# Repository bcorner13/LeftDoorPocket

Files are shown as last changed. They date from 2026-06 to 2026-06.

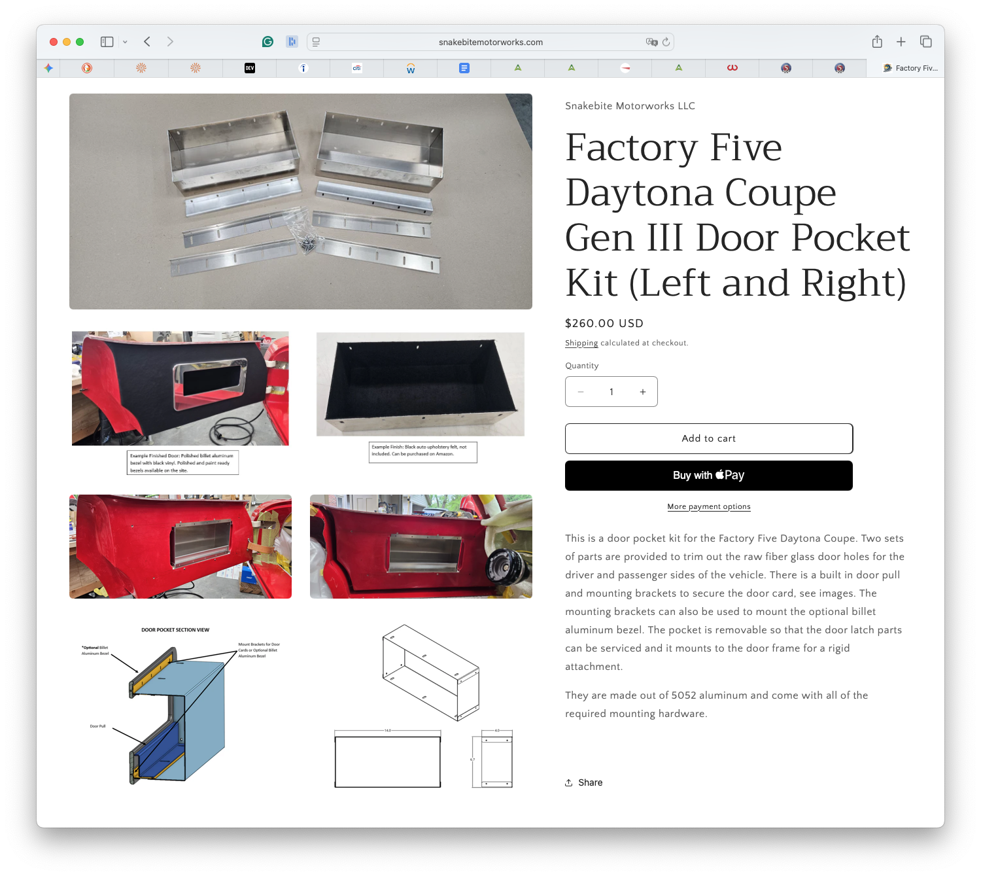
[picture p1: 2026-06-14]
images/Screenshot 2026-03-26 at 10.01.16 PM.png

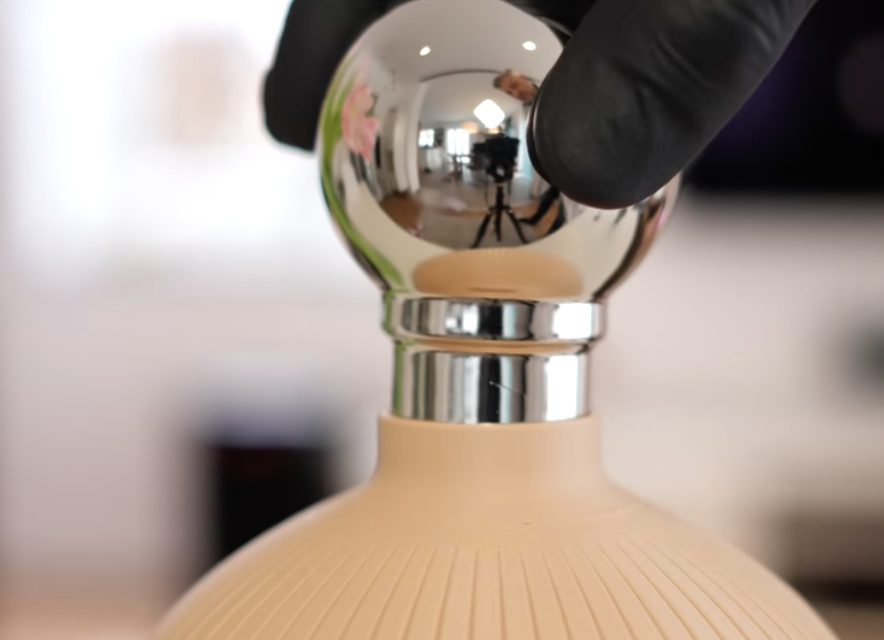
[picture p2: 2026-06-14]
images/Screenshot 2026-03-26 at 10.39.22 PM.png

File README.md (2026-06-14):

# Left Door Pocket

Parametric storage pocket / organizer for the **inside of a Daytona Coupe driver-side
door**, designed against a 3D scan of the door panel. Multi-part printed assembly
(pocket + backing plate + two modular accessories) joined with M4 heat-set inserts and
screws.

Built and printed on the **Creality K2 Plus** (PLA for test, engineering plastic for
production), per the workspace standards in `CAD_STANDARDS.md`.

## Status

- **Canonical file:** `Assembly.FCStd` (FreeCAD 1.1.2 Assembly workbench).
- Geometry + assembly complete. **Active phase: K2 Plus build-plate fit** — the
  DoorPocket and BackingPlate are 392 mm in X (42 mm over the 350 mm bed).
- **Parametric backlog:** 127 unbound dimensions across the three part files; only the
  print-bed visualization is parametric so far. See `STATE.md` and `plan.md`.

## Layout

```
LeftDoorPocket/
├── Assembly.FCStd          ← canonical top-level assembly
├── Params.FCStd            ← VarSet for cross-doc parametric expressions
├── Left Door Pocket V1.3.FCStd  ← legacy single-doc fallback (do not work in)
├── parts/                  ← per-part source bodies (DoorPocketSet, Accessory_1/2)
├── archive/                ← historical V1.0–V1.2 versions (do not touch)
├── cad_files/              ← door 3D-scan reference (.stl, .mlp)
├── macros/                 ← project .FCMacro files
├── scripts/                ← audit_parametric.py and utilities
├── 3mf/  stl/              ← print deliverables (tracked)
├── gcode/                  ← slicer output (gitignored, regenerable)
├── images/                 ← screenshots / renders
├── intent.md  plan.md  STATE.md   ← goal, plan, detailed living state
└── CLAUDE.md + standards docs      ← project + workspace rules
```

## Working in this project

1. Open `Assembly.FCStd` (it pulls in the 4 source docs via App::Link) and double-click
   the `Assembly` node to make it active.
2. All geometry must stay parametric — read `CLAUDE.md` before any change.
3. After any edit: `python3 scripts/audit_parametric.py` (authoritative; fix violations
   before committing).
4. Write changes as macros under `macros/`, not by editing FCStd XML.

See `STATE.md` for assembly architecture, lessons learned, and the full next-session
checklist.

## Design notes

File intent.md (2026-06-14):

# intent.md — Left Door Pocket

## Goal

A parametric storage pocket / organizer that mounts to the **inside of a Daytona Coupe
driver-side (left) door**, designed to fit the door panel captured by 3D scan
(`cad_files/Daytona Coupe Inside door.stl`).

The deliverable is a multi-part printed assembly:
- **DoorPocket** — the main pocket body (base, walls, internal cavity)
- **BackingPlate** — mounts the pocket to the door, carries 16 M4 heat-set inserts
- **Accessory_1 / Accessory_2** — modular insert accessories that seat in the pocket
- Hardware: 16× M4×8.15 heat inserts (press-fit, permanent) + 16× M4×25 screws (removable)

## Constraints

- Must follow `CAD_STANDARDS.md` (mm units, manifold geometry, Part/PartDesign).
- Must follow the parametric rules in `CLAUDE.md` / `~/.claude/CLAUDE.md`:
  everything driven by `Params.FCStd` VarSet, no literal sketch constraints,
  datum-plane attachment, decoupled per-interface clearances.
- Printable on the **Creality K2 Plus** (350×350×350 mm build volume).
  - ⚠️ Current DoorPocket and BackingPlate are **392 mm in X — 42 mm too long** for
    the bed. Resolving this (diagonal print vs. midline split) is the active next phase.
- Peg-in-hole and screw interfaces must use print-fit clearances (FDM-tolerant),
  not geometric tightness.

## Status

Geometry and the 1.1.2 Assembly are built (`Assembly.FCStd` canonical).
Remaining work: K2 Plus build-plate fit, then the parametric refactor backlog
(127 unbound dimensions across the three part files). See `plan.md` and `STATE.md`.

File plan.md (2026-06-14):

# plan.md — Left Door Pocket

> **Note:** This is a *retrofit* plan. The geometry and assembly already exist
> (built across sessions through 2026-05-10). This document records the realized
> design plus the remaining roadmap, so future sessions don't re-derive it.
> `STATE.md` holds the detailed, living state; this is the bootstrap-required plan view.

## PARAMETERS

Current `Params.FCStd` VarSet (3 properties — build-volume visualization only):

| Name | Type | Default | Purpose |
|---|---|---|---|
| `PrintBedX` | App::PropertyLength | 350 mm | K2 Plus build volume X |
| `PrintBedY` | App::PropertyLength | 350 mm | K2 Plus build volume Y |
| `PrintBedZ` | App::PropertyLength | 350 mm | K2 Plus build volume Z |

Parametric backlog — Params to add during the refactor (per `CLAUDE.md`):
- Pocket envelope: `LengthX`, `LengthY`, `HeightZ`, `WallThick`, `BaseThick`
- Pegs: `PegD`, `PegLength`, `PegOffsetX`, `PegOffsetY`
- Inserts/screws: `InsertBoreD`, `InsertDepth`, `ScrewClearD`
- Clearances (decoupled, one per interface):
  - `PegFitClearance` — peg-into-hole print fit
  - `BoltHoleClearance` — screw-through clearance
  - `ClearanceSide` — geometric tightness (~0.05–0.1 mm), kept separate from print fits

## FEATURE TREE

```
Assembly.FCStd  (Assembly::AssemblyObject — top level)
├── L_DoorPocket          → DoorPocketSet#Body      (GROUNDED)
├── L_Accessory_1         → Accessory_1#Body002
├── L_Accessory_2         → Accessory_2#Body003
├── SubAsm_BackingPlate   (nested Assembly — rigid unit)
│   ├── L_BackingPlate    → DoorPocketSet#Body001
│   └── Insert × 16       (M4×8.15 heat inserts)
├── Screw × 16            (M4×25, removable group)
└── PrintBed_K2Plus       (Part::Box, parametric, hidden)

Per-part source docs (parts/):
- DoorPocketSet.FCStd → Body (DoorPocket) + Body001 (BackingPlate, cross-body SubShapeBinder)
- Accessory_1.FCStd   → Body002
- Accessory_2.FCStd   → Body003
```

## CONSTRAINT STRATEGY

- Each per-part FCStd is refactored body-by-body (start simplest: Accessory_1).
- Every dimensional constraint bound via `setExpression` to `<<Params>>#VarSet.<name>`.
- Sketches attached to **datum planes** (convert any feature-face attachments / Deactivated
  MapMode peg datums to origin-plane-offset datums with parametric offsets).
- Clearances decoupled per interface — never overload one clearance variable.
- App::Link components use `LinkTransform=True` so intrinsic placements compose.

## VALIDATION

1. `python3 scripts/audit_parametric.py` — must report zero issues per file
   (current backlog: 127 unbound across the three part docs).
2. Geometry watertight / manifold (CAD_STANDARDS.md).
3. Build-plate fit: each printable body ≤ 350 mm on the K2 Plus, OR a validated
   diagonal orientation / midline split.
4. Assembly recompute clean; exploded view resolves; no DAG warnings.

## ROADMAP (active → deferred)

1. **K2 Plus fit** (active) — diagonal-print test of the 392 mm DoorPocket/BackingPlate;
   fall back to a parametric midline split if artifacts are unacceptable.
2. **Parametric refactor** — body-by-body, audit-clean each before moving on.
3. **Assembly polish** — explicit fixed joints, per-step instruction screenshots.

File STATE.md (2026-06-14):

# LeftDoorPocket — Project State

**Last updated:** 2026-05-10 (end of restructure session)
**Canonical working file:** `Assembly.FCStd`
**Status:** Restructure complete. **Next phase: K2 Plus build-plate fit.**

## File layout

```
LeftDoorPocket/
├── Assembly.FCStd                              ← top-level Assembly (1.1.2 workbench)
├── Params.FCStd                                ← VarSet for cross-doc parametric expressions
├── Left Door Pocket V1.3.FCStd                 ← legacy fallback (DO NOT WORK IN)
├── Left Door Pocket V1.3.Session-2026-05-09.FCStd  ← snapshot taken before LCS strip
├── parts/
│   ├── DoorPocketSet.FCStd                     ← contains Body (DoorPocket) + Body001 (BackingPlate)
│   ├── Accessory_1.FCStd                       ← Body002
│   └── Accessory_2.FCStd                       ← Body003
├── archive/
│   ├── Left Door Pocket.FCStd
│   ├── Left Door Pocket V1.0/V1.1/V1.1_backup/V1.2.FCStd
├── assembly_placements.json                    ← sidecar: body Y=27.39 record
├── scripts/audit_parametric.py                 ← parametric debt auditor
├── macros/create_params.FCMacro                ← bootstrap macro for Params.FCStd
├── CLAUDE.md                                   ← project rules
├── CAD_STANDARDS.md                            ← commercial design rules
├── MCP_TOOLS_REFERENCE.md                      ← FreeCAD MCP tool reference
└── STATE.md                                    ← this file
```

## Assembly architecture

```
Assembly  (Assembly::AssemblyObject, internal name "AssemblyV2")
├── L_DoorPocket               (App::Link → DoorPocketSet#Body, GROUNDED)
├── L_Accessory_1              (App::Link → Accessory_1#Body002)
├── L_Accessory_2              (App::Link → Accessory_2#Body003)
├── SubAsm_BackingPlate        (Assembly::AssemblyObject — sub-assembly, rigid unit)
│   ├── L_BackingPlate         (App::Link → DoorPocketSet#Body001)
│   └── Insert × 16            (M4x8.15 heat inserts, Part::FeaturePython)
├── Screw × 16                 (M4x25 screws — selectable as group)
├── Joints / GroundedJoint     (L_DoorPocket grounded)
└── PrintBed_K2Plus            (Part::Box, parametric, hidden by default)
```

**Component counts** (verified via UtilsAssembly):
- Main assembly: 36 components total
- Sub-assembly: 17 components (1 BackingPlate + 16 inserts)

**Why this architecture:**
- `SubAsm_BackingPlate` is its own `Assembly::AssemblyObject` so it can have its **own nested exploded view** (separate the 16 inserts from the BackingPlate as a sub-step).
- Heat inserts are press-fit (permanent) → rigid sub-assembly with BackingPlate.
- Screws are removable → kept as individual main-assembly components so they can be selected as a group and dragged out.
- All link Placements composed correctly via `LinkTransform=True`. BackingPlate's intrinsic Y=27.39mm carries through automatically.

## Parametric state

`Params.FCStd` VarSet currently has **3 properties**:
- `PrintBedX`, `PrintBedY`, `PrintBedZ` — all 350mm (K2 Plus build volume)

Bound to `Assembly.FCStd:PrintBed_K2Plus` for build-volume visualization.

**Per-part files have NO parametric bindings yet**:
- `parts/DoorPocketSet.FCStd`: 72 unbound issues
- `parts/Accessory_1.FCStd`: 24 unbound issues
- `parts/Accessory_2.FCStd`: 31 unbound issues
- Total: **127 unbound dimensional constraints + DAG-risk attachments + unconstrained sketches**

These are the parametric refactor backlog. Run `python3 scripts/audit_parametric.py` for the full list.

## Known cosmetic issues (not blocking)

1. **Internal Name `AssemblyV2`** vs Label "Assembly" — caused by name-collision avoidance during the V1.3 App::Part → Assembly::AssemblyObject conversion. User sees correct label in the tree; only matters for scripting.
2. **`*.bin (0 bytes)` warnings on doc load** — empty SuppressedShape/InternalShape cache files left over from the per-part prune passes. Geometry resolves fine via recompute. To clean up: open each per-part FCStd, force a full recompute, save.
3. **`Assembly001` may reappear** if user runs `Assembly_CreateAssembly` again (creates a new empty Assembly with internal name "Assembly" since that's free). Just delete it from the tree.

## Lessons learned this session (worth remembering)

- **FreeCAD's RunInitGuiPy exec context** does NOT set `__file__` and does NOT share module-level names with class methods or deferred callbacks. Stub-loader pattern (separate `_workbench.py` exec'd from `InitGui.py` with explicit shared namespace) is the correct fix. Applied to `FreeCADMCPAgent` addon at both local + 5TB locations.
- **`App::Link` `LinkTransform`** defaults to `False` in 1.1, meaning the linked object's intrinsic Placement is NOT applied — only the link's own Placement. Set to `True` to compose properly. We hit this with the BackingPlate Y=27.39 ghost gap.
- **Assembly workbench requires `Assembly::AssemblyObject` typeId**, not `App::Part`. V1.3-era "Assembly" objects were App::Part shells — they LOOK assembly-like but `Assembly_CreateView`, `Assembly_CreateBom`, and joint commands stay grayed out.
- **Tree clicks don't register with the exploded-view dialog.** Selection paths must be rooted at the Assembly object name; clicking the App::Link in the tree generates a path rooted at the link, which `getComponentReference` rejects. **Always click on a face in the 3D view.**
- **`Assembly_InsertLink` GUI command and `addObject("App::Link")` produce equivalent components.** No metadata difference. The workbench identifies components by type + parent + LinkedObject.
- **Cross-body `SubShapeBinder`** in BackingPlate (binds outline to DoorPocket.Fillet001.Face27) is why we kept those two bodies in one FCStd file (`DoorPocketSet.FCStd`) rather than splitting them. Cross-doc binders work but add complexity; we'll revisit in the parametric pass.

## ⚠️ Build-plate fit assessment (next phase)

K2 Plus build volume: **350×350×350 mm**

| Part | Size (X×Y×Z mm) | Fits K2 Plus? |
|---|---|---|
| **DoorPocket** | **392 × 126 × 157** | ❌ **42mm too long in X** |
| **BackingPlate** | **392 × 9 × 157** | ❌ **42mm too long in X** |
| Accessory_1 | 69.7 × 70 × 35 | ✅ |
| Accessory_2 | 70 × 70 × 60 | ✅ |

**The two main bodies do not fit on the K2 Plus.** Options for next phase:

1. **Diagonal print** — 350√2 ≈ 495mm available across the bed diagonal. Need to verify print orientation works for the geometry (door pocket cavity opening, overhangs).
2. **Parametric scale-down** — make `LengthX` a Param and reduce. Affects functional fit on the actual door panel — probably non-starter without door-fit redesign.
3. **Split design** — divide DoorPocket and BackingPlate at midpoint with a mating interface (dovetail, dowels, glue joint). Two halves, each ≤200mm, joined post-print.
4. **Switch printer** — Saturn 4 is smaller (218×123×260 typical for Mk2/Ultra), so probably worse. No clear option here.

**Likely next-session direction:** option 1 first (cheapest test — just orientation), fall back to option 3 (design work) if angled printing introduces unacceptable artifacts on the door pocket cavity walls.

## Open follow-ups (for next session)

**Phase: K2 Plus fit**
- [ ] Test diagonal-orientation print of DoorPocket on K2 Plus (slicer simulation first)
- [ ] If diagonal fails → design a midline split for DoorPocket + matching BackingPlate split
- [ ] Verify Accessory_1, Accessory_2 print orientation (peg overhang, surface finish on cylinder side)

**Phase: parametric refactor (deferred)**
- [ ] Run audit, work body-by-body. Start with Accessory_1 (24 issues, simplest).
- [ ] Convert peg datums (`PegPlane_L`/`PegPlane_R`, `DP2_PegL`/`DP2_PegR`) from Deactivated MapMode to attached-to-origin-plane with parametric offsets.
- [ ] Bind every dimensional constraint via `setExpression` to `<<Params>>#VarSet.<name>`.
- [ ] Decouple clearances into per-interface vars: `PegFitClearance`, `BoltHoleClearance`.
- [ ] Re-run `scripts/audit_parametric.py` between bodies, target zero issues per file.

**Phase: assembly polish (low priority)**
- [ ] Add `Joint_Fixed` between L_DoorPocket and SubAsm_BackingPlate (replace the ad-hoc grounded-only setup with explicit kinematic constraints)
- [ ] Decide screw motion: keep them as individual movable components or group via fixed joints
- [ ] Build the per-step assembly-instruction screenshots (the documentation script)
- [ ] Optional: write the frame-export Python script for exploded-view animation

## How to resume next session

1. Open `Assembly.FCStd` (it auto-loads the 4 source docs via App::Link).
2. Double-click the `Assembly` node in the tree to make it active (FreeCAD doesn't persist active state).
3. Confirm the geometry looks right — DoorPocket grounded, BackingPlate sub-asm flush, accessories in their sockets.
4. Then start the K2 Plus fit work.

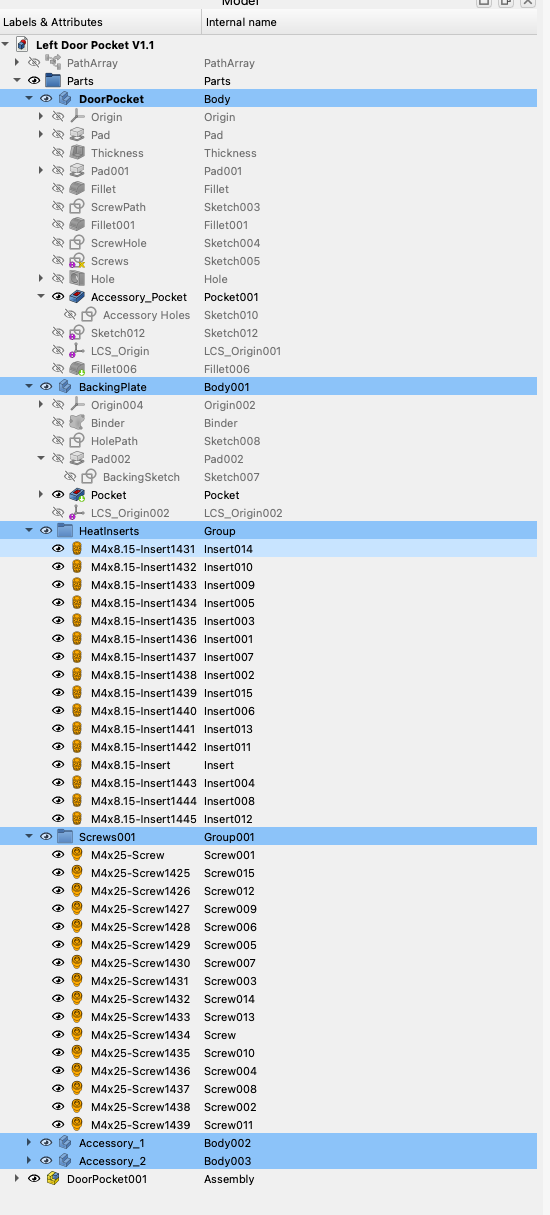
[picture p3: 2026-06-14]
images/Screenshot 2026-03-26 at 10.19.09 PM.png

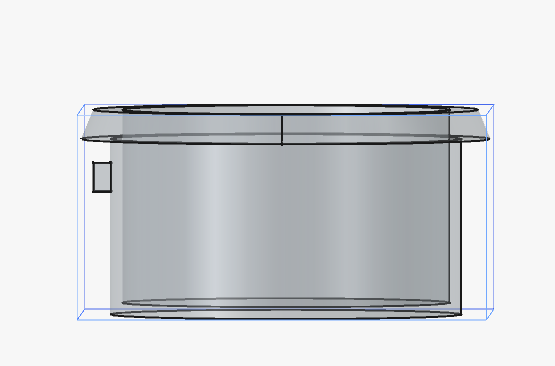
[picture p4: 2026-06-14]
images/Screenshot 2026-03-26 at 4.24.34 PM.png

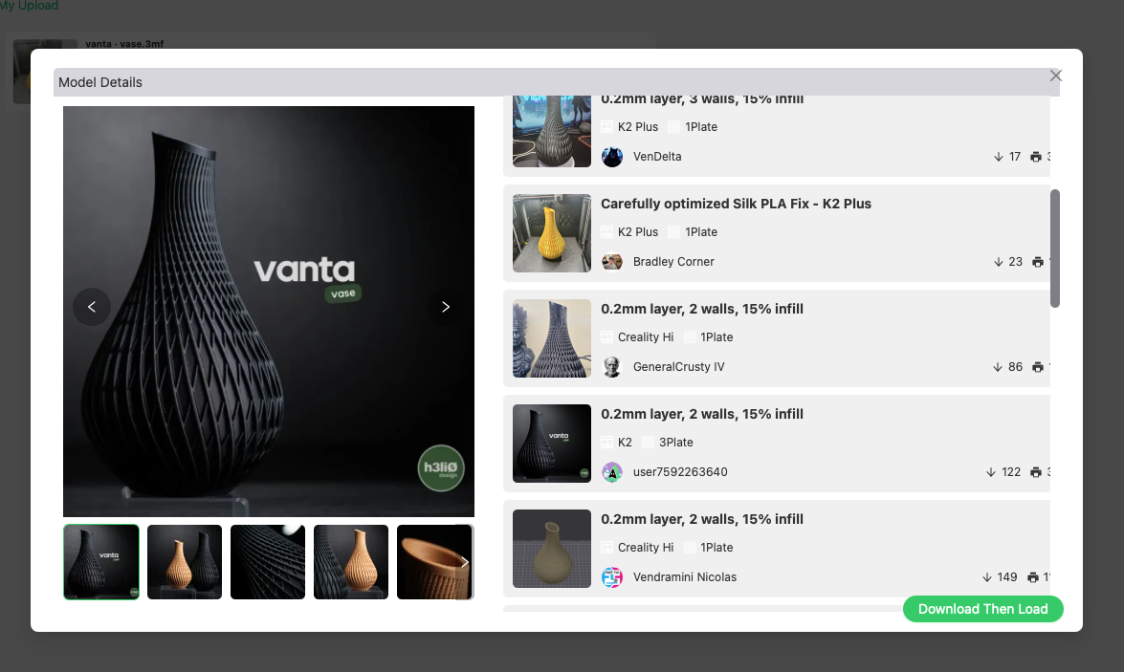
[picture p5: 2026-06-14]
images/Screenshot 2026-03-27 at 3.15.48 AM.png

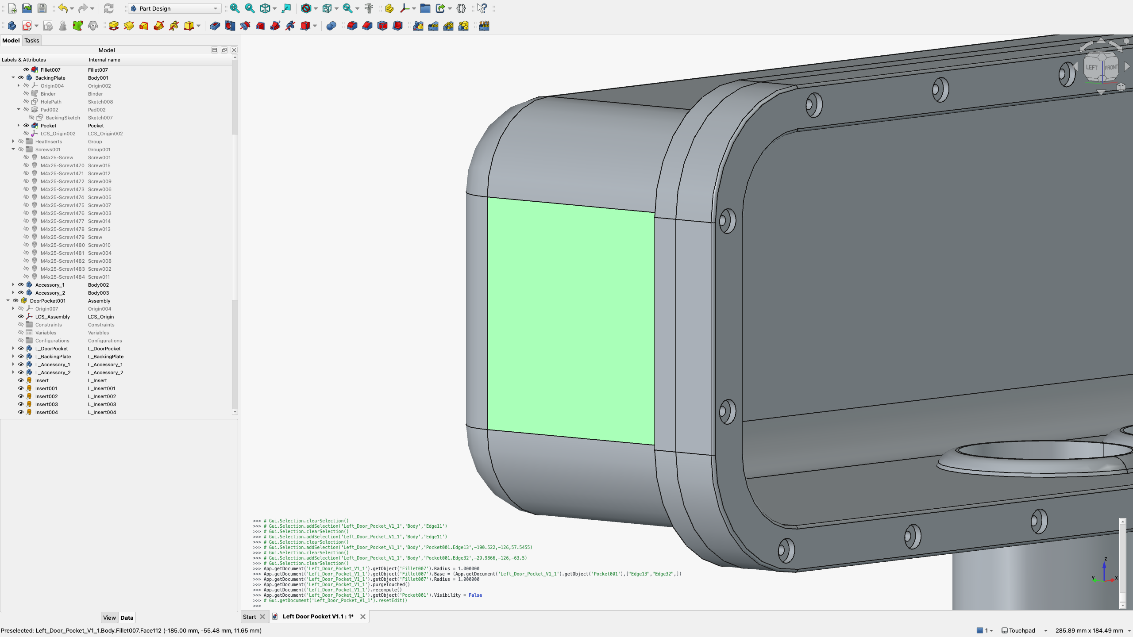
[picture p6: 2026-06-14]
images/Screenshot 2026-03-26 at 10.34.55 PM.png

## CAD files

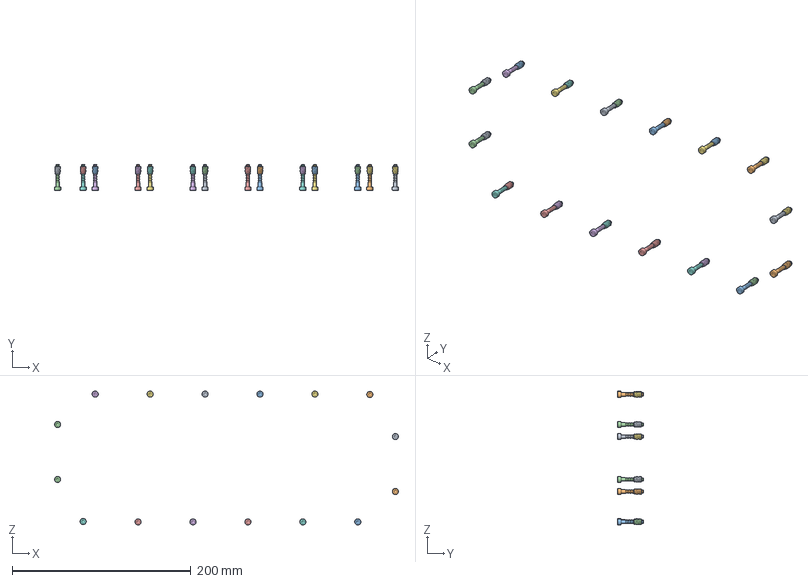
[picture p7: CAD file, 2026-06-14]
Assembly.FCStd
385.0 x 29.0 x 149.9 mm
M4x8.15-Insert1624
M4x8.15-Insert1620
M4x8.15-Insert1619
M4x8.15-Insert1615
M4x8.15-Insert1613
M4x8.15-Insert1611
M4x8.15-Insert1617
M4x8.15-Insert1612
M4x8.15-Insert1625
M4x8.15-Insert1616
M4x8.15-Insert1623
M4x8.15-Insert1621
M4x8.15-Insert
M4x8.15-Insert1614
M4x8.15-Insert1618
M4x8.15-Insert1622
M4x25-Screw
M4x25-Screw1589
M4x25-Screw1586
M4x25-Screw1583
M4x25-Screw1580
M4x25-Screw1579
M4x25-Screw1581
M4x25-Screw1577
M4x25-Screw1588
M4x25-Screw1587
M4x25-Screw1575
M4x25-Screw1584
M4x25-Screw1578
M4x25-Screw1582
M4x25-Screw1576
M4x25-Screw1585

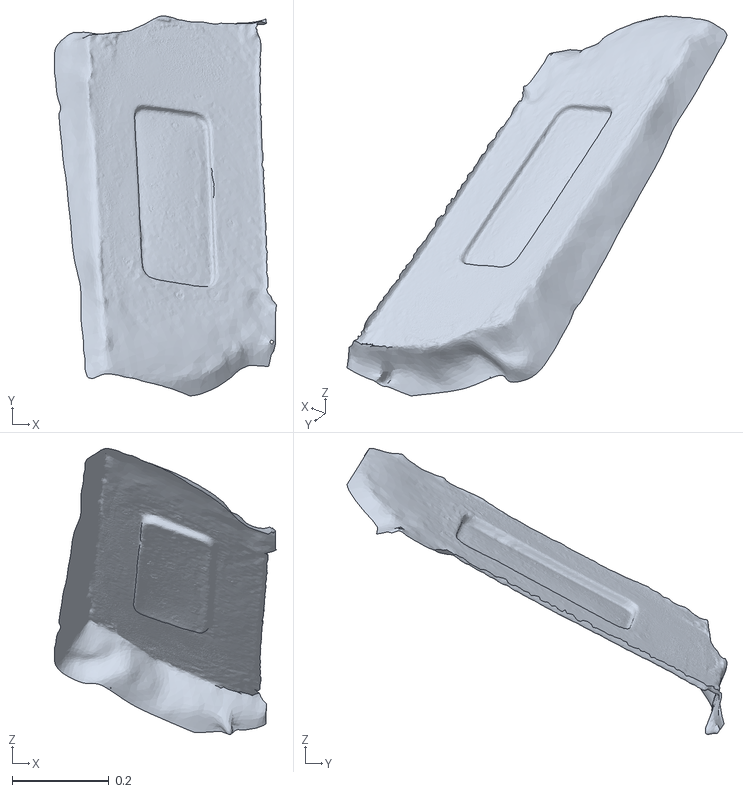
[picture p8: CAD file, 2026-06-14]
cad_files/Daytona Coupe Inside door.stl
0.461 x 0.787 x 0.593

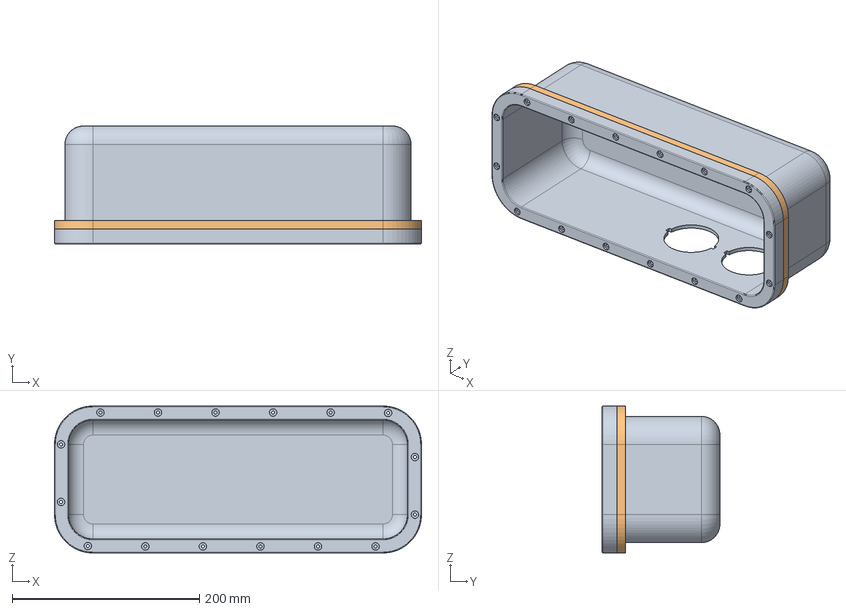
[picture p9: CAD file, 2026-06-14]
parts/DoorPocketSet.FCStd
392.0 x 126.0 x 157.0 mm
DoorPocket
BackingPlate

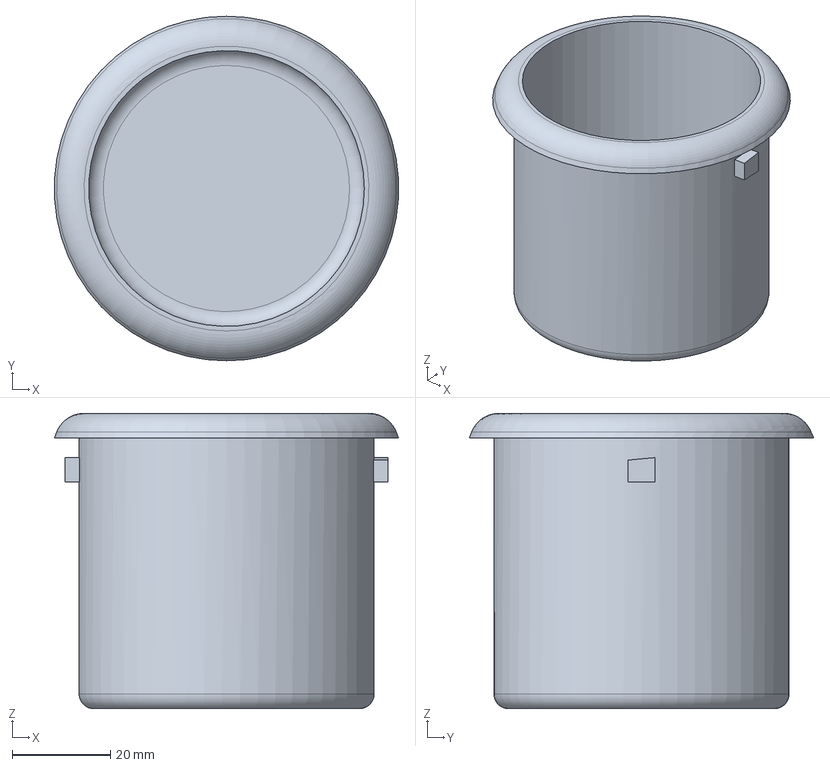
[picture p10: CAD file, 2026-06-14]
parts/Accessory_2.FCStd
69.9 x 70.0 x 60.0 mm

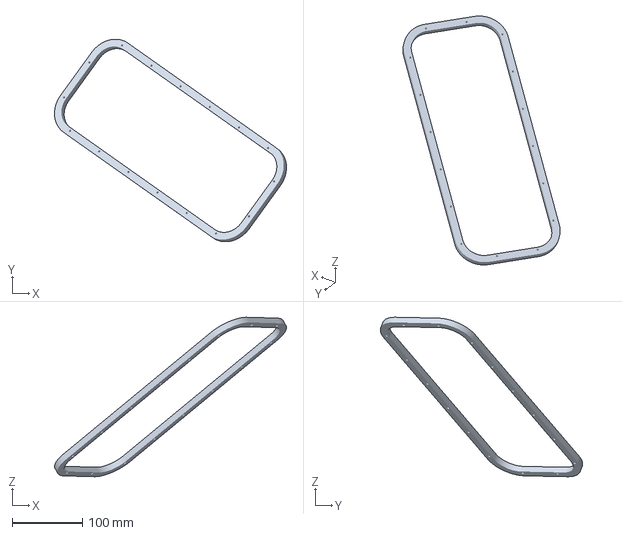
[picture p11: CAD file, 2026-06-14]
Left Door Pocket V1.1-BackingPlate.3mf
331.4 x 289.2 x 227.9 mm

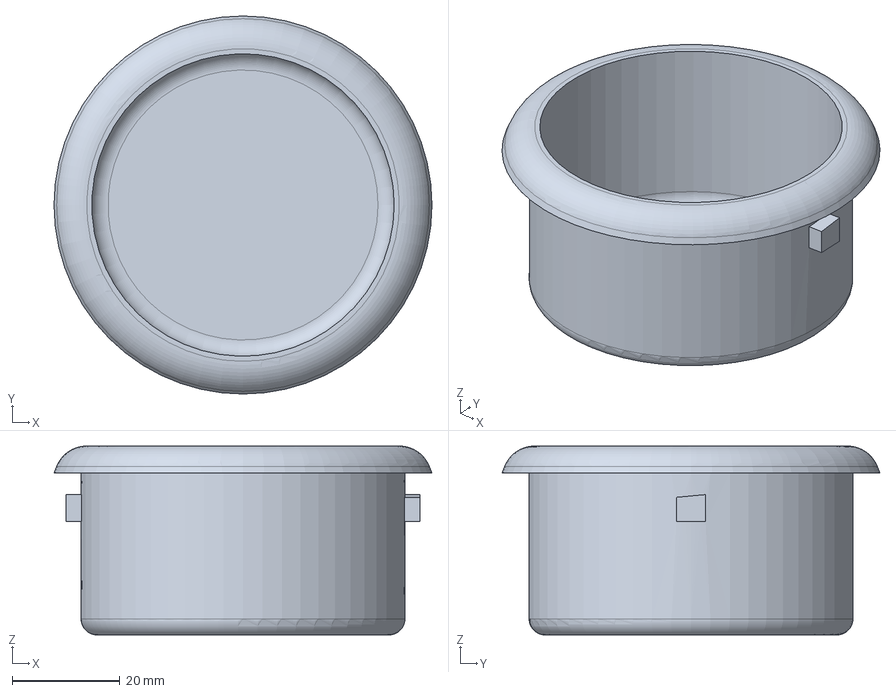
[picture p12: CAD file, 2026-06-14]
parts/Accessory_1.FCStd
70.0 x 70.0 x 35.0 mm

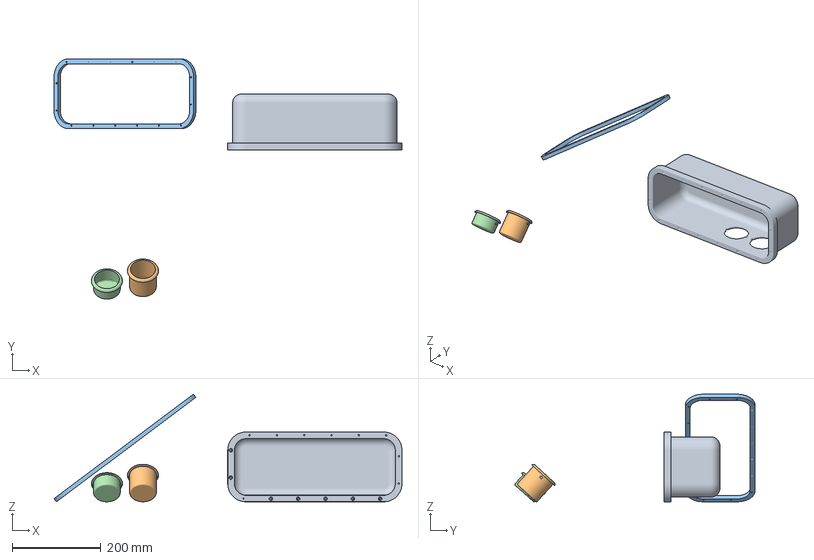
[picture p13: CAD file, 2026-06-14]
Left Door Pocket V1.2.3mf
782.8 x 540.3 x 242.1 mm
DoorInset
TallCup
BackingPlate
ChangeCup

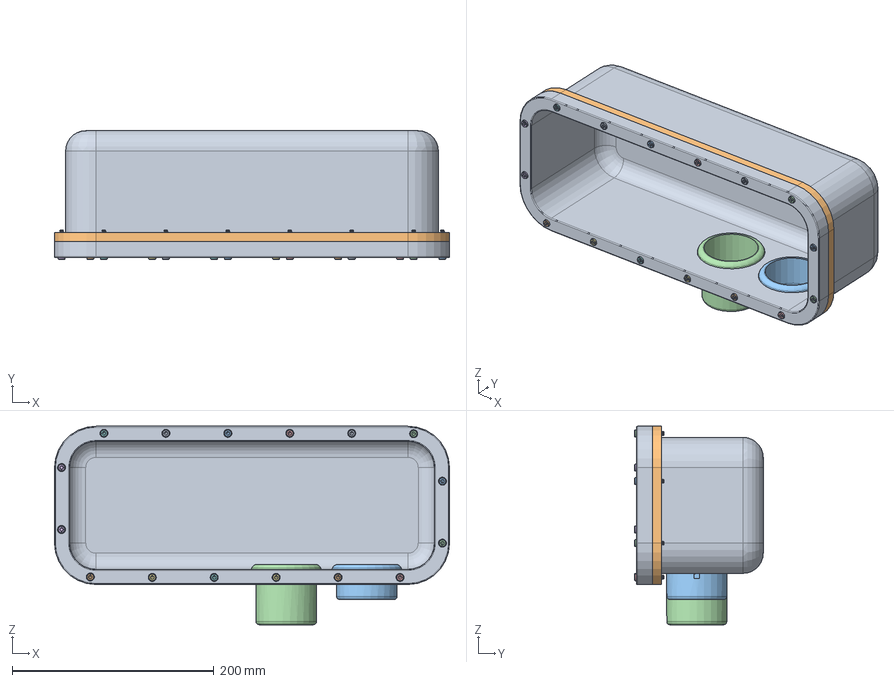
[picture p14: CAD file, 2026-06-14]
Left Door Pocket V1.3.FCStd
392.0 x 127.6 x 197.0 mm
DoorPocket
BackingPlate
M4x8.15-Insert1581
M4x8.15-Insert1582
M4x8.15-Insert1583
M4x8.15-Insert1584
M4x8.15-Insert1585
M4x8.15-Insert1586
M4x8.15-Insert1587
M4x8.15-Insert1588
M4x8.15-Insert1589
M4x8.15-Insert1590
M4x8.15-Insert1591
M4x8.15-Insert1592
M4x8.15-Insert
M4x8.15-Insert1593
M4x8.15-Insert1594
M4x8.15-Insert1595
M4x25-Screw
M4x25-Screw1545
M4x25-Screw1546
M4x25-Screw1547
M4x25-Screw1548
M4x25-Screw1549
M4x25-Screw1550
M4x25-Screw1551
M4x25-Screw1552
M4x25-Screw1553
M4x25-Screw1554
M4x25-Screw1555
M4x25-Screw1556
M4x25-Screw1557
M4x25-Screw1558
M4x25-Screw1559
Accessory_1
Accessory_2

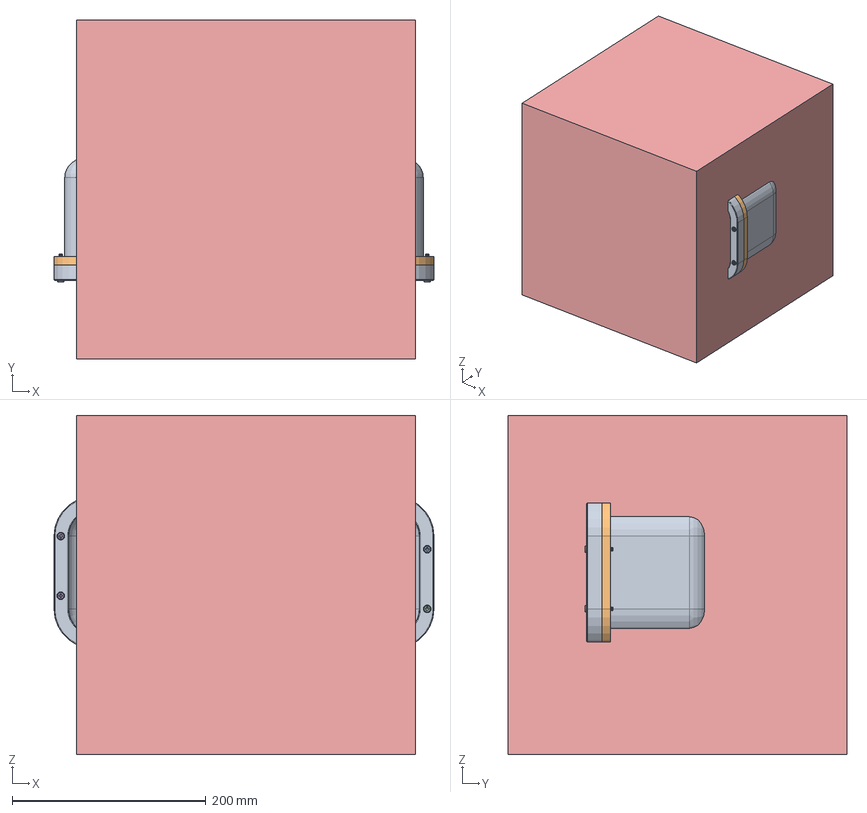
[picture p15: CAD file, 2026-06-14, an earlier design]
archive/Left Door Pocket V1.1.FCStd
392.0 x 350.0 x 350.0 mm
DoorPocket x 2
BackingPlate x 2
M4x8.15-Insert1491 x 2
M4x8.15-Insert1492 x 2
M4x8.15-Insert1493 x 2
M4x8.15-Insert1494 x 2
M4x8.15-Insert1495 x 2
M4x8.15-Insert1496 x 2
M4x8.15-Insert1497 x 2
M4x8.15-Insert1498 x 2
M4x8.15-Insert1499 x 2
M4x8.15-Insert1500 x 2
M4x8.15-Insert1501 x 2
M4x8.15-Insert1502 x 2
M4x8.15-Insert x 2
M4x8.15-Insert1503 x 2
M4x8.15-Insert1504 x 2
M4x8.15-Insert1505 x 2
M4x25-Screw
M4x25-Screw1485
M4x25-Screw1486
M4x25-Screw1487
M4x25-Screw1488
M4x25-Screw1489
M4x25-Screw1490
M4x25-Screw1491
M4x25-Screw1492
M4x25-Screw1493
M4x25-Screw1494
M4x25-Screw1495
M4x25-Screw1496
M4x25-Screw1497
M4x25-Screw1498
M4x25-Screw1499
Accessory_1 x 2
Accessory_2 x 2

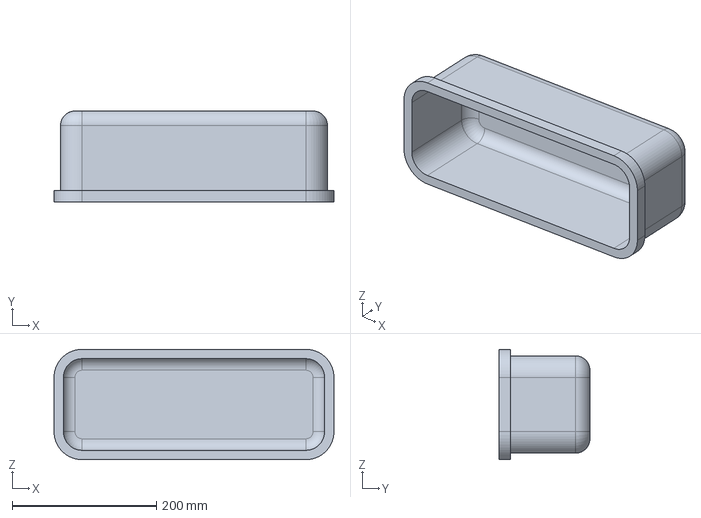
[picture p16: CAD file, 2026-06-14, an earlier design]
archive/Left Door Pocket V1.0.FCStd
388.0 x 126.0 x 153.0 mm

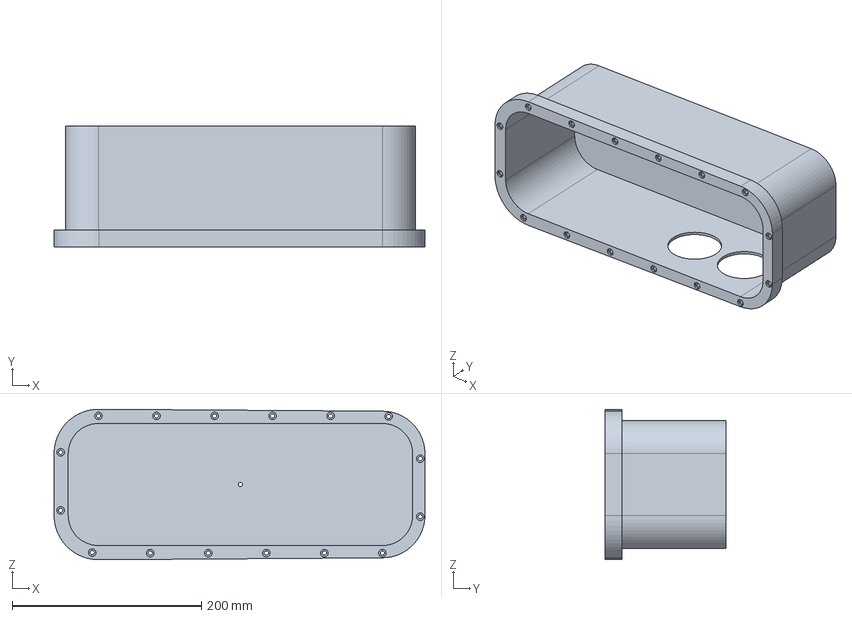
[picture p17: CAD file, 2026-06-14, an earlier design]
archive/Left Door Pocket.FCStd
392.0 x 128.0 x 159.0 mm

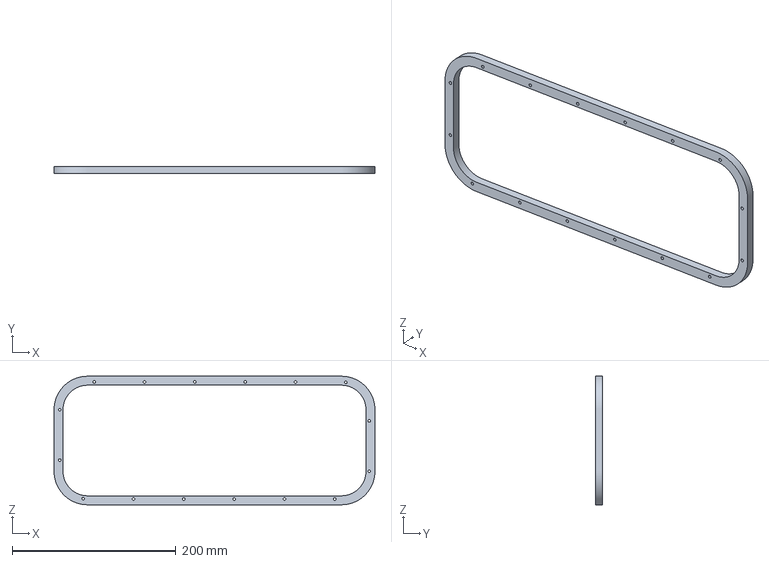
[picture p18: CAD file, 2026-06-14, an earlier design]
archive/Left Door Pocket V1.1-BackingPlate.3mf
392.0 x 9.00 x 157.0 mm

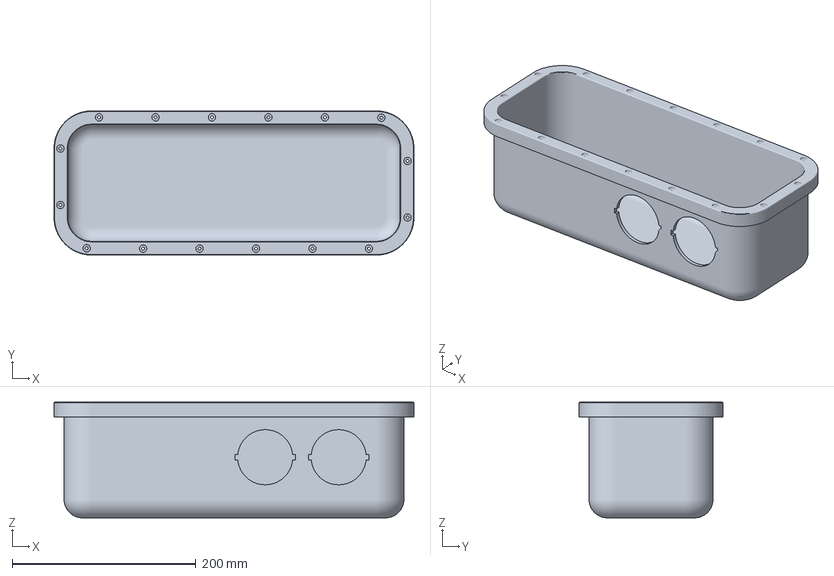
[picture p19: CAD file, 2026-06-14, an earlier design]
Left Door Pocket V1.1.3mf
392.0 x 157.0 x 126.0 mm

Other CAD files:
Params.FCStd
archive/Left Door Pocket V1.1_backup.FCStd
archive/Left Door Pocket V1.2.FCStd
archive/Left Door Pocket V1.1.3mf
